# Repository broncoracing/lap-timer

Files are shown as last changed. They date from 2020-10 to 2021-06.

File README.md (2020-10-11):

# lap-timer
GPS Lap Timer

## Project: 

A PCB with a built in GPS module and CAN bus hardware to log and transmit lap times over CAN bus. 

## Hardware: 

### Electronics: 

- 4 Layer PCB made in Altium 
- Main microcontroller: STM32F103C8T6
- CAN transceiver: SN65HVD230DR
- GPS Module: UBLOX M8Q
  This can be changed, but ideally one like this with an internal antenna will be used. 
  Connected to STM32 via UART/serial
- Voltage regulation on board (can be simple linear regulators)
- JST PH connector for CAN bus and 14V power
  Since this will be repeatedly connected/disconnected, I’m open to other options
- 2 pin connector for button
- 2 two pin connectors for two status LEDs (power and GPS status)	

### Enclosure:

- 3D printable enclosure 
- Quick mounting to the main roll hoop (above driver’s head). Ideally this will be a toolless mounting system. 
- 1 single plug to connect
- Waterproof button accessible from outside

## Software: 

- STM32 is in charge of the CAN bus control and the GPS module
- Continuously queries GPS module for correct location (highest rate possible)
- Calculates time from when car starts moving from set start coordinates, until car passes within a specified 
  range of the start coordinates. Factor in speed to  improve accuracy 
- Fancy features for the future:
  - Log the whole run, and map out the track on a laptop with a heatmap of speed. 

## Usage at a a test track: 

1. Install GPS lap timer to roll hoop
2. Plug it in
3. Wait for GPS ready LED to be solid (in your code)
4. Roll car to starting line
5. Press the “teach” button to tell the module where the starting line is. 
6. Use existing telemetry software to view lap times

The main STM32 and CAN bus schematic can be stolen from the brake light hardware. Remove all of the LEDs obviously and add in the UBLOX module.

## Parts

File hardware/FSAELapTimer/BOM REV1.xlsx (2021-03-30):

Designator | Quantity | PartNumber
BT1 | 1 | MS621FE-FL11E
C1, C12, C14 | 3 | C1608X5R1A106K080AC
C2, C3, C4, C10, C11, C13 | 6 | CGA3E2X7R1H104K080AA
C5, C6, C9 | 3 | C0603C105K3PAC7867
C7, C8 | 2 | 08051A200JAT2A
C15, C16, C17, C18 | 4 | CGA5L3X5R1H106K160AB
C19 | 1 | CGA3E2X7R1H104K080AA
C20 | 1 | GRM31MR71H105KA88L
D1 | 1 | SD0603S040S0R2
J1 | 1 | FTSH-105-01-L-DV-007-K
LED1 | 1 | 150120RS75000
LED2 | 1 | 150120GS75000
LED3 | 1 | 150120BS75000
P1 | 1 | 610108249121
P2 | 1 | B4B-PH-K-S(LF)(SN)
R1, R6 | 2 | CRCW060310K0FKEB
R2, R4 | 2 | RT0603BRD0710RL
R3 | 1 | RT0603FRE073K3L
R5 | 1 | ERJ-8ENF1004V
R7, R8, R9 | 3 | TNPW0603200RBEEA
SW1, SW2 | 2 | PTS645SM43SMTR92 LFS
U1 | 1 | SAM-M8Q-0-10
U2 | 1 | STM32L432KCU6
U3 | 1 | ASM330LHHTR
U4 | 1 | SN65HVD230DR
U5 | 1 | ADP3335ARMZ-3.3RL7
Y1 | 1 | ABS07-120-32.768KHZ-T

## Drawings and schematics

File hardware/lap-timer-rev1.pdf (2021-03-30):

3V31 2

# 3.3k ² ¹

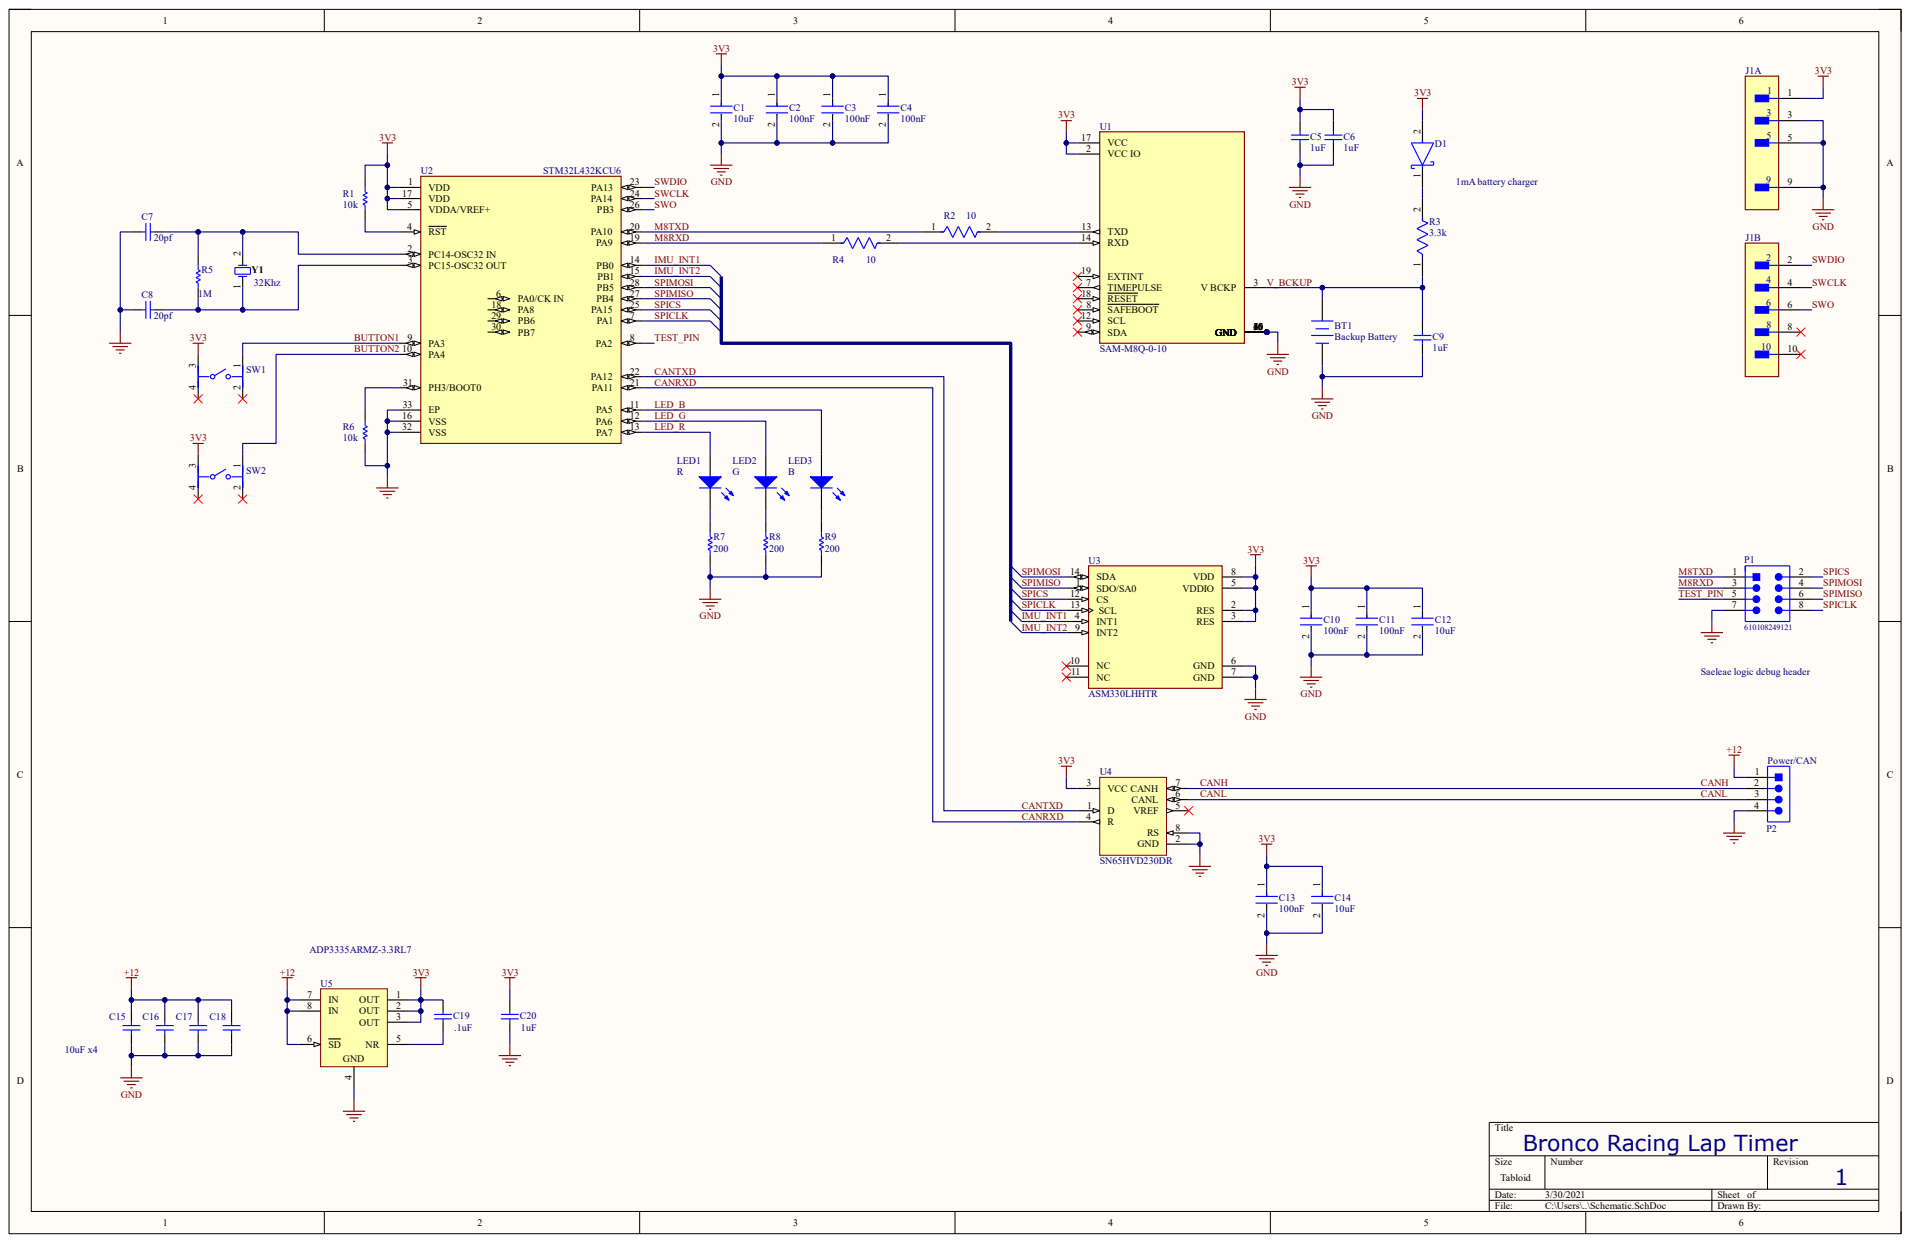
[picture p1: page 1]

Saeleae logic debug header

Title
Bronco Racing Lap Timer

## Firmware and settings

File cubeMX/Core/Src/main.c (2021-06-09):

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
/* Includes ------------------------------------------------------------------*/
#include "main.h"
#include "dma.h"
#include "i2c.h"
#include "spi.h"
#include "usart.h"
#include "gpio.h"

/* USER CODE BEGIN Includes */
#include <stdio.h>
#include "SEGGER_RTT.h"
/* USER CODE END Includes */


/* USER CODE BEGIN PV */
char buff[512];
/* USER CODE END PV */

void SystemClock_Config(void);
/**
  * @brief  The application entry point.
  * @retval int
  */
int main(void)
{
  /* MCU Configuration--------------------------------------------------------*/

  /* Reset of all peripherals, Initializes the Flash interface and the Systick. */
  HAL_Init();

  /* Configure the system clock */
  SystemClock_Config();

  /* Initialize all configured peripherals */
  MX_GPIO_Init();
  MX_DMA_Init();
  MX_I2C1_Init();
  MX_USART1_UART_Init();
  MX_SPI1_Init();
  /* USER CODE BEGIN 2 */
  SEGGER_RTT_ConfigUpBuffer(0,NULL,NULL,0, SEGGER_RTT_MODE_BLOCK_IF_FIFO_FULL);
  HAL_GPIO_WritePin(PWR_LED_GPIO_Port,PWR_LED_Pin,1);
  HAL_GPIO_WritePin(PWR_LED_GPIO_Port,PWR_LED_Pin,0);
  HAL_UART_Receive_DMA(&huart1, buff, sizeof(buff));
  /* USER CODE END 2 */

  /* Infinite loop */
  /* USER CODE BEGIN WHILE */
  while (1)
  {
    
    /* USER CODE END WHILE */

    /* USER CODE BEGIN 3 */
  }
  /* USER CODE END 3 */
}

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


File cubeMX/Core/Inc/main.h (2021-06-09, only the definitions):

#define BUTTON1_Pin GPIO_PIN_3
#define BUTTON1_GPIO_Port GPIOA
#define BUTTON2_Pin GPIO_PIN_4
#define BUTTON2_GPIO_Port GPIOA
#define GPS_LED_Pin GPIO_PIN_5
#define GPS_LED_GPIO_Port GPIOA
#define PWR_LED_Pin GPIO_PIN_6
#define PWR_LED_GPIO_Port GPIOA
#define AUX_LED_Pin GPIO_PIN_7
#define AUX_LED_GPIO_Port GPIOA
#define IMU_INT1_Pin GPIO_PIN_0
#define IMU_INT1_GPIO_Port GPIOB
#define IMU_INT2_Pin GPIO_PIN_1
#define IMU_INT2_GPIO_Port GPIOB
#define GPS_TX_Pin GPIO_PIN_9
#define GPS_TX_GPIO_Port GPIOA
#define GPS_RX_Pin GPIO_PIN_10
#define GPS_RX_GPIO_Port GPIOA
#define GPS_SDL_Pin GPIO_PIN_6
#define GPS_SDL_GPIO_Port GPIOB
#define GPS_SDA_Pin GPIO_PIN_7
#define GPS_SDA_GPIO_Port GPIOB

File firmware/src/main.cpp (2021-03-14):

#include <mbed.h>

//definitions and inits

//read vss

//read position over pins 16/17

//store start position when button pushed

//when vehicle starts moving from vss and position start timer
//determine direction of motion here

//when gps coords approach start coords within x () meters, determine distance to 
//start coords and calculate remaining time to coords using speed and acceleration

//send calculated lap time over can

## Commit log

2020-10-13 Copied thermocouple schematic and PCB. Started cleanup and removal of unneeded components
    [FSAELapTimer.PrjPcb, Thermocouple Connector PCB Lib.PcbLib, ThermocoupleInterfaceBOM.xlsx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]
2020-10-16 More schematic cleanup
    [FSAELapTimer.PrjPcb, mainSchem.SchDoc]
2021-03-14 Added imu
    [mainSchem.SchDoc]
2021-03-28 added STM32CubeMX project
    this allows for easy setup of pinMap or toolchain if we use cubeMX
2021-03-28 finalize pin selection and schematic capture
    [FSAELapTimer.PrjPcb, mainSchem.SchDoc]
2021-03-29 Finished initial schematic, added backup battery and charger
    [mainSchem.SchDoc]
2021-03-29 swapped SAM M8Q and ASM330 for parts with footprints
    [PCB.PcbDoc, Schematic.SchDoc, mainSchem.SchDoc]
2021-03-29 started routing
    [FSAELapTimer.PrjPcb, PCB.PcbDoc, Schematic.SchDoc]
2021-03-29 initial route complete
    [PCB.PcbDoc, Schematic.SchDoc]
2021-03-30 added rule to increase distance between all pads and via stitches
    [PCB.PcbDoc, Schematic.SchDoc]
2021-03-30 removed silktosilkclearence rule
    [PCB.PcbDoc]
2021-03-30 added BOM and Gerbers
    [BOM REV1.xlsx, PCB.PcbDoc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]
2021-03-31 regenerate gerbers
    [FSAELapTimer.PrjPcb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]

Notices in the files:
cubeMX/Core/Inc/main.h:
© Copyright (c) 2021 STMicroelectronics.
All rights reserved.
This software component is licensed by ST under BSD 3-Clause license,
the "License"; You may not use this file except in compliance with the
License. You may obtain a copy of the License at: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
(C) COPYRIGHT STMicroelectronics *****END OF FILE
